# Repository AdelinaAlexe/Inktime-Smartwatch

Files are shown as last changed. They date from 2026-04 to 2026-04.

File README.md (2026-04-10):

# InkTime Smartwatch

**Author:** Adelina Maria Alexe

**License:** [GNU GPLv3](LICENSE)  

---

## Architecture & Block Diagram

The core architecture relies on the **nRF52840 SoC** to manage all peripheral communication and wireless connectivity. To guarantee system stability and maximize battery utilization, power delivery is strictly regulated by an **RT6160 Buck-Boost converter**, which maintains a constant 3.3V rail for all active components.

**Block Diagram**
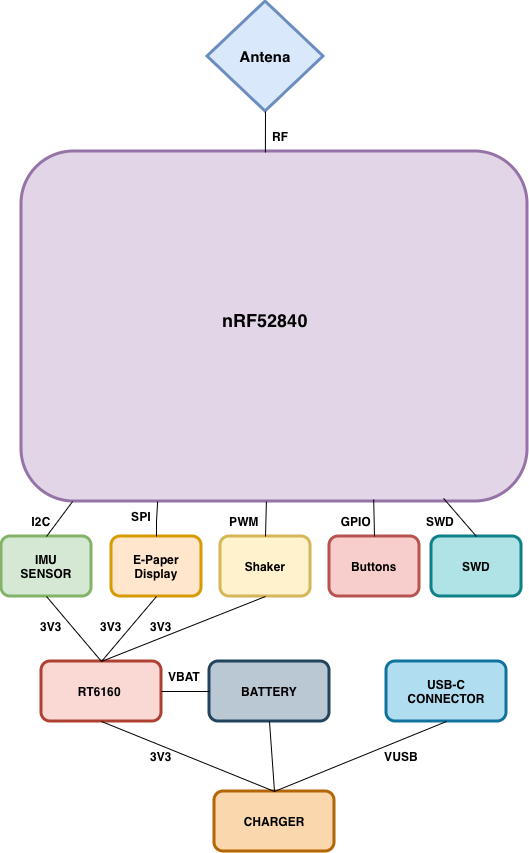
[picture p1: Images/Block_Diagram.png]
Block Diagram


---

## Bill of Materials

| Designator(s) | JLC | Package | Description | Referance |
| :--- | :--- | :--- | :--- | :--- |
| **U1** | C3606653 | QFN-48 | nRF52840 BLE 5.4 Microcontroller | [Referance](https://www.lcsc.com/datasheet/C3606653.pdf) |
| **IC1** | C3682423 | DSBGA-8 | BQ25180 Li-Ion/Polymer Charger IC | [Referance](https://www.ti.com/cn/lit/ds/symlink/bq25180.pdf?ts=1775594237116) |
| **IC2** | C81079 | DSBGA-9 | DRV2605 Haptic Motor Driver | [Referance](https://www.ti.com/cn/lit/gpn/drv2605) |
| **IC3** | C189517 | LGA-12 | BMA423 Triaxial Accelerometer (IMU) | [Referance](https://www.lcsc.com/datasheet/C189517.pdf) |
| **IC9** | C7065276 | WLCSP-15B | RT6160 Buck-Boost Regulator | [Referance](https://wmsc.lcsc.com/wmsc/upload/file/pdf/v2/lcsc/2312271436_Richtek-Tech-RT6160AWSC_C7065276.pdf) |
| **U2** | C2682616 | DFN-8-EP | MAX17048G I2C Battery Fuel Gauge | [Referance](https://www.lcsc.com/datasheet/lcsc_datasheet_2410121738_Analog-Devices-Inc--Maxim-Integrated-MAX17048G-T10_C2682616.pdf) |
| **J1** | C122434 | SMD 0.5mm | 24-Pin FPC Connector (E-Paper Display) | [Referance](https://www.molex.com/content/dam/molex/molex-dot-com/products/automated/en-us/salesdrawingpdf/503/503480/5034802400_sd.pdf) |
| **J4** | C709357 | SMD Type-C | Type-C USB 16P Connector | [Referance](https://www.lcsc.com/datasheet/lcsc_datasheet_2404191039_Shenzhen-Kinghelm-Elec-KH-TYPE-C-16P_C709357.pdf) |
| **ANT1** | C2917717 | 1206 | 2.45GHz Patch Antenna (0.5dBi) | [Referance](https://www.lcsc.com/datasheet/lcsc_datasheet_2404021210_Johanson-Dielectrics-2450AT18B100E_C2917717.pdf) |
| **X1** | C9009 | SMD3225 | 32MHz Crystal Oscillator | [Referance](https://www.lcsc.com/datasheet/lcsc_datasheet_2403291504_YXC-Crystal-Oscillators-X322532MOB4SI_C9009.pdf) |
| **X2** | C32346 | SMD3215 | 32.768kHz Crystal Oscillator | [Referance](https://www.lcsc.com/datasheet/lcsc_datasheet_2404180925_Seiko-Epson-Q13FC13500004_C32346.pdf) |
| **SW_UP, SW_ENT, SW_DN** | C569760 | SMD 3.9x2.9 | Tactile Switches (IP67) | [Referance](https://wmsc.lcsc.com/wmsc/upload/file/pdf/v2/lcsc/2301111010_PANASONIC-EVPAKE31A_C569760.pdf) |
| **D2, D4, D5** | C82046 | SOD-123 | MBR0530 Schottky Diode (30V, 0.5A) | [Referance](https://www.lcsc.com/datasheet/lcsc_datasheet_2304140030_onsemi-MBR0530T1G_C82046.pdf) |
| **D3** | C2969755 | SOT-23-6L | USBLC6-2SC6Y ESD Protection Array | [Referance](https://wmsc.lcsc.com/wmsc/upload/file/pdf/v2/lcsc/2211080730_STMicroelectronics-USBLC6-2SC6Y_C2969755.pdf) |
| **Q1** | C2564 | TO-220AB | IRF4905PBF P-Channel MOSFET | [Referance](https://www.lcsc.com/datasheet/lcsc_datasheet_1809041724_Infineon-Technologies-IRF4905PBF_C2564.pdf) |
| **Q3** | C469327 | SOT-323 | Si1308EDL N-Channel MOSFET | [Referance](https://www.lcsc.com/datasheet/lcsc_datasheet_1912202016_Vishay-Intertech-SI1308EDL-T1-GE3_C469327.pdf) |
| **L1, L2, L3** | C12669 | 0402 | Generic Chip Inductor (27nH) | [Referance](https://www.lcsc.com/datasheet/lcsc_datasheet_2304140030_Murata-Electronics-LQG15HS27NJ02D_C12669.pdf) |
| **L5** | C1329646 | SMD 4.8x4.8 | 4.7uH Power Inductor (AEC-Q200) | [Referance](https://wmsc.lcsc.com/wmsc/upload/file/pdf/v2/lcsc/2304140030_BOURNS-SRR4828A-4R7Y_C1329646.pdf) |
| **L7** | C5832368 | 1008 | 470nH Power Inductor | [Referance](https://wmsc.lcsc.com/wmsc/upload/file/pdf/v2/lcsc/2306021632_cjiang--Changjiang-Microelectronics-Tech-FTC252012SR47MBCA_C5832368.pdf) |
| **J2** | C90533 | P=1mm | 6 POS Cable Adapter | [Referance](https://wmsc.lcsc.com/wmsc/upload/file/pdf/v2/lcsc/1810141506_LX-FFC6P1-0mm7CM_C90533.pdf) |
| **Resistors (Group)** | C3920633 | 0201 | 7.68k Thin Film Resistors (±0.5%) | [Referance](https://wmsc.lcsc.com/wmsc/upload/file/pdf/v2/lcsc/2404081048_TE-Connectivity-CPF0201B511RE1_C3920633.pdf) |
| **Capacitors (Group)** | C9900156064 | 0201 | Generic Chip Capacitors | [Referance](https://ds.yuden.co.jp/TYCOMPAS/or/download?pn=MLAST063SCG681JFNA01&fileType=CA) |
| **C23, C27, C34, C42** | C21012218 | - | Special Chip Capacitors | [Referance](https://jlc-prod-smt.oss-eu-central-1.aliyuncs.com/smtDataManualFile/8603520985945550848-C21012218.pdf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) |
| **C24, C25, C33, C39** | C9900179830 | 0402 | 0402 Metric Capacitors | N/A |
| **SJ1** | N/A | Copper | Solder Jumper (Leave Open) | N/A |
| **TP** | N/A | Copper | Test Pads | N/A |

---

## Hardware Specifications & Functionality

InkTime is engineered from the ground up for extreme power efficiency. By pairing a deeply optimized microcontroller with an E-Ink display, the device maintains readability in direct sunlight while drawing virtually no power during static image display.

### -> Processing & Connectivity
* **Microcontroller (Nordic nRF52840):** Features an ARM Cortex-M4F core clocked at 64 MHz. It provides native support for Bluetooth 5.4 (BLE) and boasts exceptional deep-sleep currents in the micro-amp range. 

### -> Power Management System
* **Charging Interface:** The **BQ25180** IC handles USB-C battery charging utilizing a strict Constant Current/Constant Voltage (CC/CV) profile, alongside integrated overvoltage and thermal protection.
* **Voltage Regulation:** We opted for the **RT6160** Buck-Boost converter over a standard LDO. This allows the system to maintain a rock-solid **3.3V** output even when the Li-Po battery voltage sags down to 3.0V, squeezing every last drop of usable capacity from the cell.
* **Battery Monitoring:** The **MAX17048G** Fuel Gauge interfaces via I2C to provide high-resolution State of Charge (SoC) metrics without requiring complex shunt resistor calculations.

### -> Peripherals & Busses
* **SPI Bus (Display):** Dedicated entirely to the 1.54" E-Paper display via a 24-pin FPC connector (J1). SPI ensures the high bandwidth needed for screen refreshes without bottlenecking other sensors.
* **I2C Bus (Sensors):** A shared I2C bus routes data from the **BMA423** IMU (used for step counting and wake-on-wrist-raise), the **MAX17048G** fuel gauge, and the **DRV2605YZFR** haptic driver.
* **Haptics:** Silent, localized haptic feedback is generated by a vibration motor driven by the **DRV2605YZFR** via PWM signals from the MCU.

### -> Power Consumption & Autonomy Analysis
The device is powered by a compact **250 mAh Li-Po cell** (Akyga LP502030). Given the E-Ink display's zero-power static state, the system's current draw is highly optimized:

* **Sleep State (MCU + BLE Advertising):** ~35 µA
* **Active Sensor Polling:** ~120 µA
* **Display Refresh Cost (Averaged per minute):** ~25 µA
* **Estimated Average Current (I_avg):** 180 µA (0.18 mA)

**Theoretical Battery Life:** `T = 250 mAh / 0.18 mA ≈ 1389 hours`

Accounting for real-world environmental factors, battery degradation, and dynamic haptic usage, the practical autonomy is rated at **9 to 14 days** per charge.

---

## MCU Pinout & Interface Mapping

| Interface / Component | Signal | nRF52840 Pin | I/O | Engineering Rationale |
| :--- | :--- | :--- | :--- | :--- |
| **E-Ink Display** | SPI SCK | **P0.11** | Output | High-speed clock mapped to Port 0 for EasyDMA access. |
| **E-Ink Display** | SPI MOSI | **P0.12** | Output | Display data transmission. |
| **E-Ink Display** | SPI CS | **P0.13** | Output | Active-low Chip Select. |
| **E-Ink Display** | Data/Command | **P0.14** | Output | Toggles between command modes and payload data. |
| **E-Ink Display** | Reset | **P0.15** | Output | Hardware reset trigger for E-Ink initialization. |
| **E-Ink Display** | Busy | **P0.16** | Input | Halts MCU operations while the display refreshes. |
| **I2C Bus** | SDA | **P0.26** | I/O | Shared data line for IMU, Fuel Gauge, and Haptics. |
| **I2C Bus** | SCL | **P0.27** | Output | Shared clock line optimized for low-power I2C routing. |
| **Button (Up)** | GPIO | **P1.07** | Input | Isolated on Port 1 to prevent high-speed signal noise. |
| **Button (Enter)** | GPIO | **P1.08** | Input | Includes internal pull-up resistor. |
| **Button (Down)** | GPIO | **P1.09** | Input | UI navigation control. |
| **Haptic Motor** | PWM | **P1.02** | Output | Modulates vibration intensity via PWM. |
| **PMIC Control** | DC/DC EN | **P0.18** | Output | Enables/Disables the RT6160 during extreme deep sleep. |
| **IMU Sensor** | INT1 | **P0.25** | Input | Hardware interrupt designated for "double-tap" wake up. |

### Design Justifications:
- **Port Segregation:** Port 0 is strictly allocated to high-speed digital busses (SPI/I2C) to leverage Nordic's **EasyDMA**, offloading data transfer from the CPU. Port 1 is reserved for physical buttons, providing physical layout isolation from high-frequency switching noise, thereby preventing false button triggers (ghosting).
- **SPI Trace Routing:** Pins P0.11 through P0.16 were selected due to their physical grouping on the silicon die, allowing for a tight, length-matched routing channel to the FPC connector.
- **NFC Provisioning:** Pins P0.09 and P0.10 were deliberately left disconnected. Their internal capacitance differs from standard GPIOs due to their native NFC capabilities. Keeping them free leaves the door open for future hardware revisions featuring contactless technology.

---

## PCB Design Log & Decisions

The PCB layout adheres to strict Design for Manufacturing (DFM) tolerances required for high-density wearable electronics:

* **Single-Layer Component Placement:** Due to severe vertical clearance constraints inside the chassis, **all 49 components are mounted on the TOP layer**. The BOTTOM layer is primarily utilized for an unbroken ground plane and non-critical signal routing.
* **Miniaturization (0201 Packages):** To achieve the required routing density on a single layer, all standard passive components (resistors, small capacitors) were downsized to **0201** imperial footprints.
* **Signal Integrity & Decoupling:** **100nF** bypass capacitors are placed aggressively close—within **0.5mm**—to the power pins of the nRF52840 to minimize parasitic loop inductance.
* **Trace Width Constraints:** Power delivery rails (VCC, 3V3, VBAT) are routed at a robust **0.3mm** width to prevent voltage drops during peak current spikes (e.g., haptic motor activation or BLE transmission). Standard data traces are kept at **0.15mm**.
* **RF Optimization (Keep-Out & Stitching):** A strict keep-out zone (void of any copper, traces, or ground planes) was enforced through all PCB layers directly beneath the 2.4GHz chip antenna. Additionally, heavy **via stitching** was applied across the board—particularly around the RF path—to tie the top and bottom ground planes together, drastically lowering reference impedance.

---

## Hardware Renderings & Visuals

**Final Design**
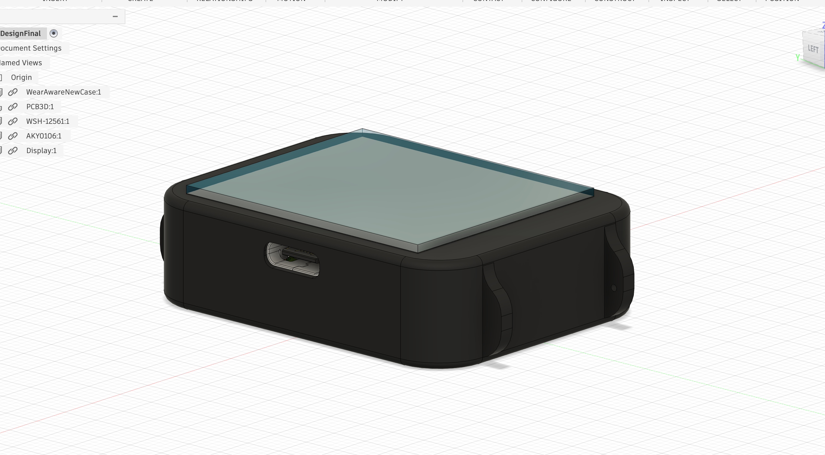
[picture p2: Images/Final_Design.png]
Final Design


**PCB 3D**
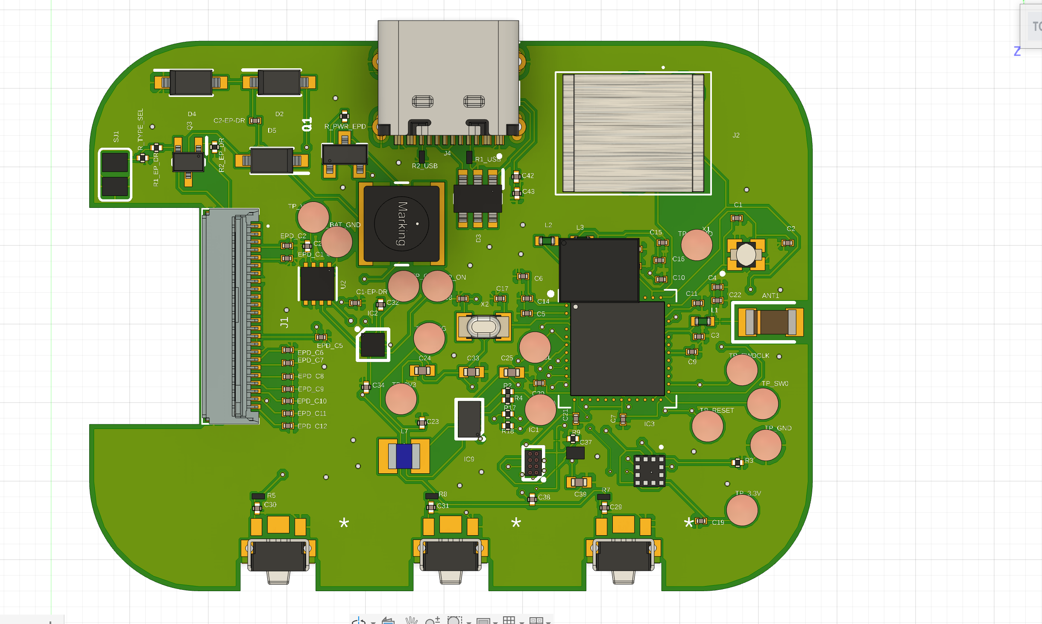
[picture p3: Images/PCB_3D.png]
PCB 3D


**Final Design Exploded**
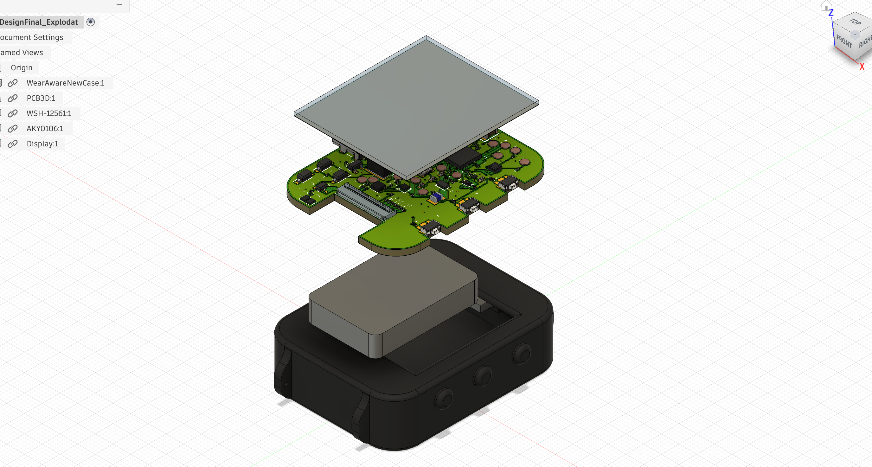
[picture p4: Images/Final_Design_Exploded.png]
Exploded View


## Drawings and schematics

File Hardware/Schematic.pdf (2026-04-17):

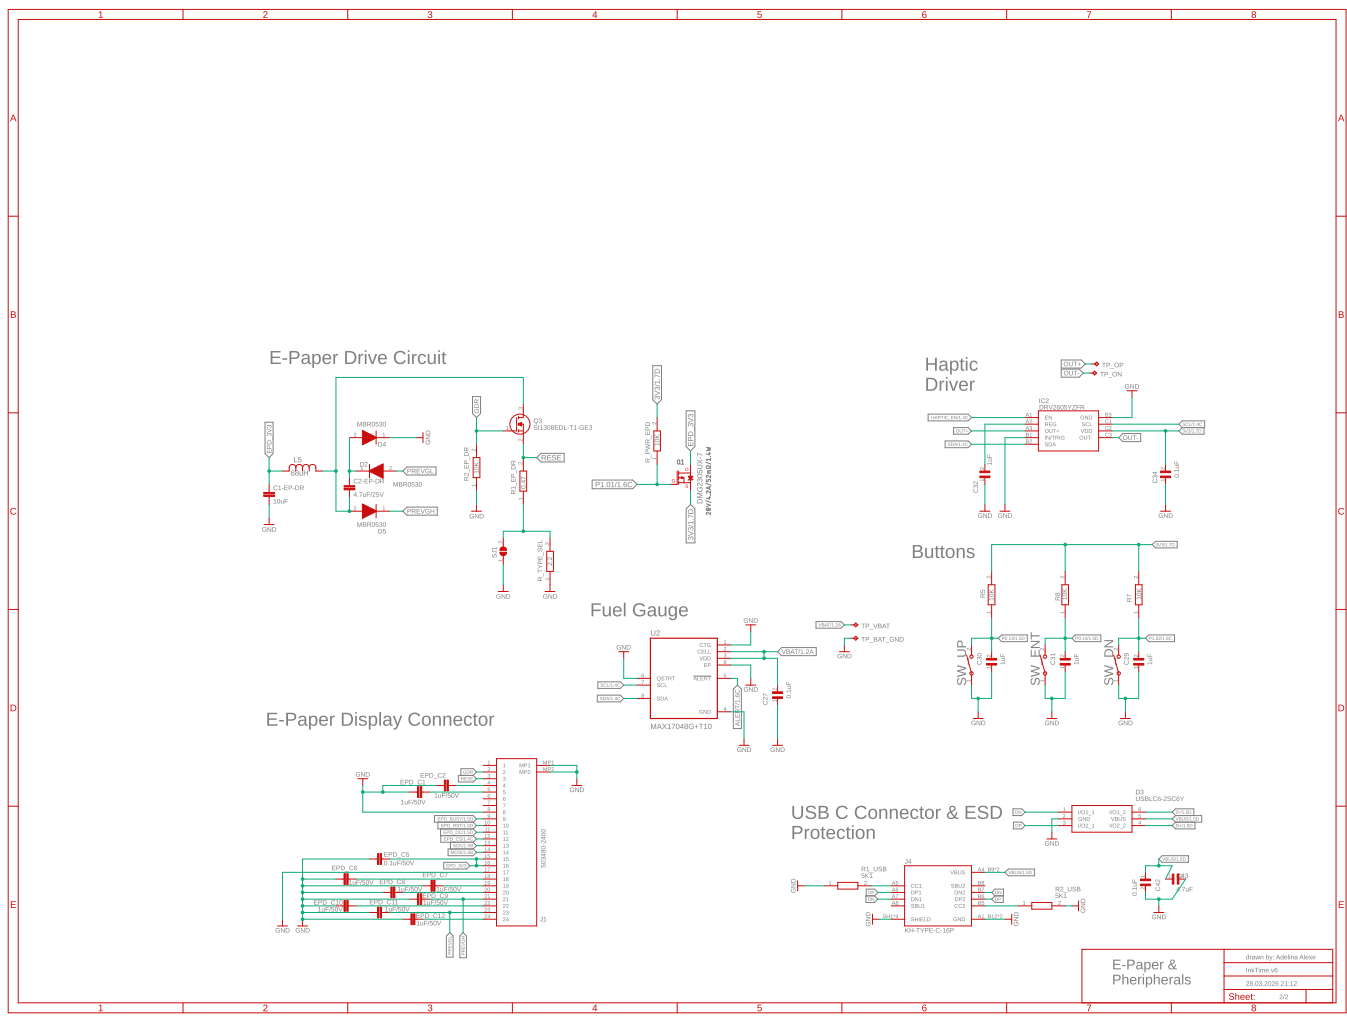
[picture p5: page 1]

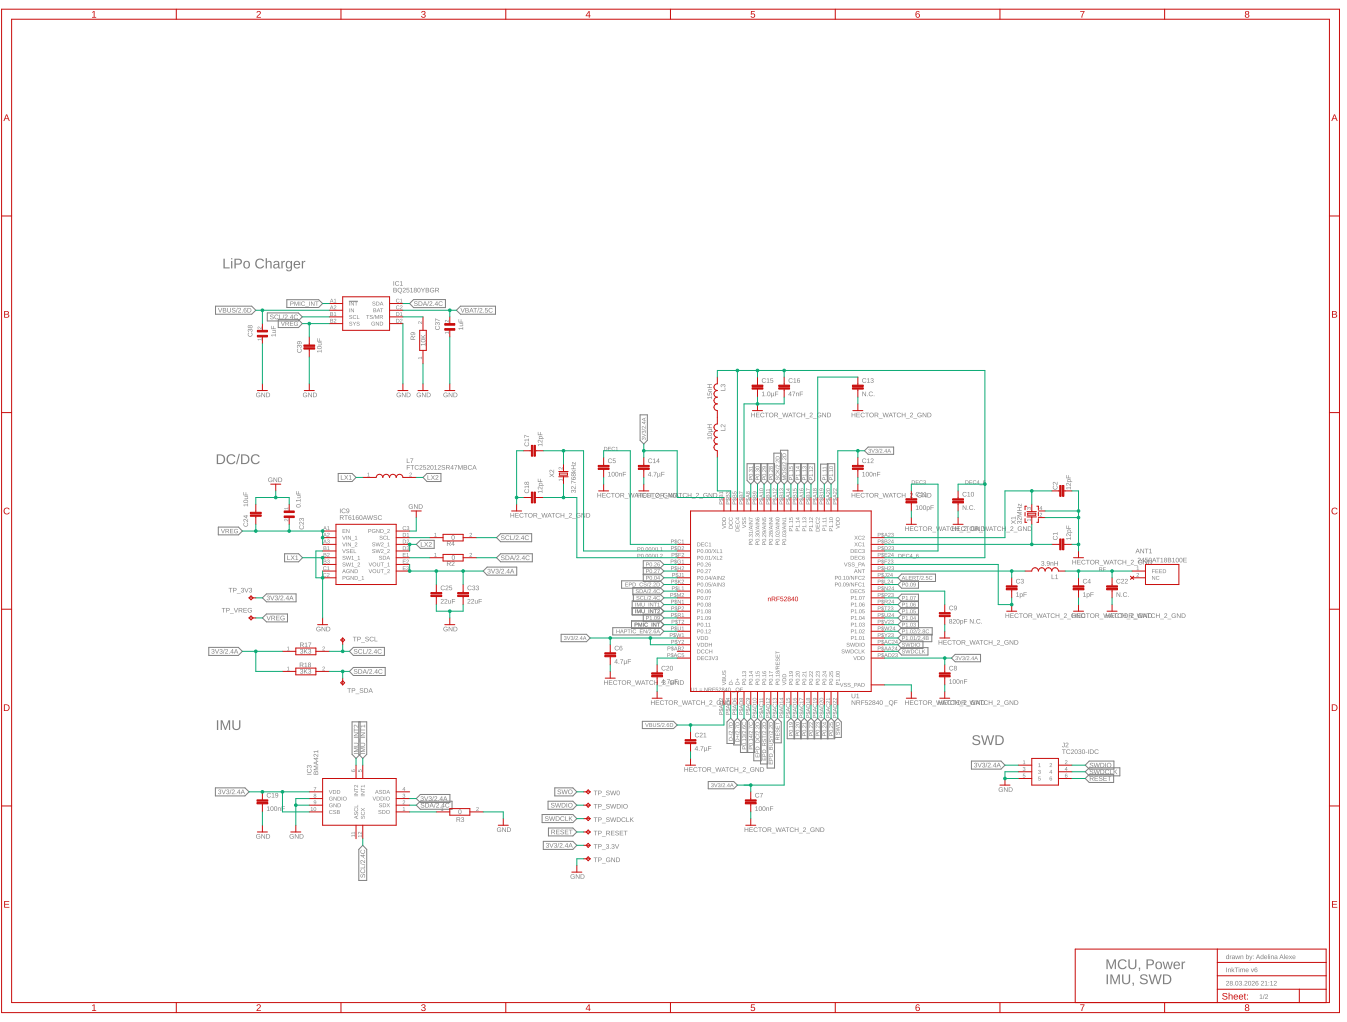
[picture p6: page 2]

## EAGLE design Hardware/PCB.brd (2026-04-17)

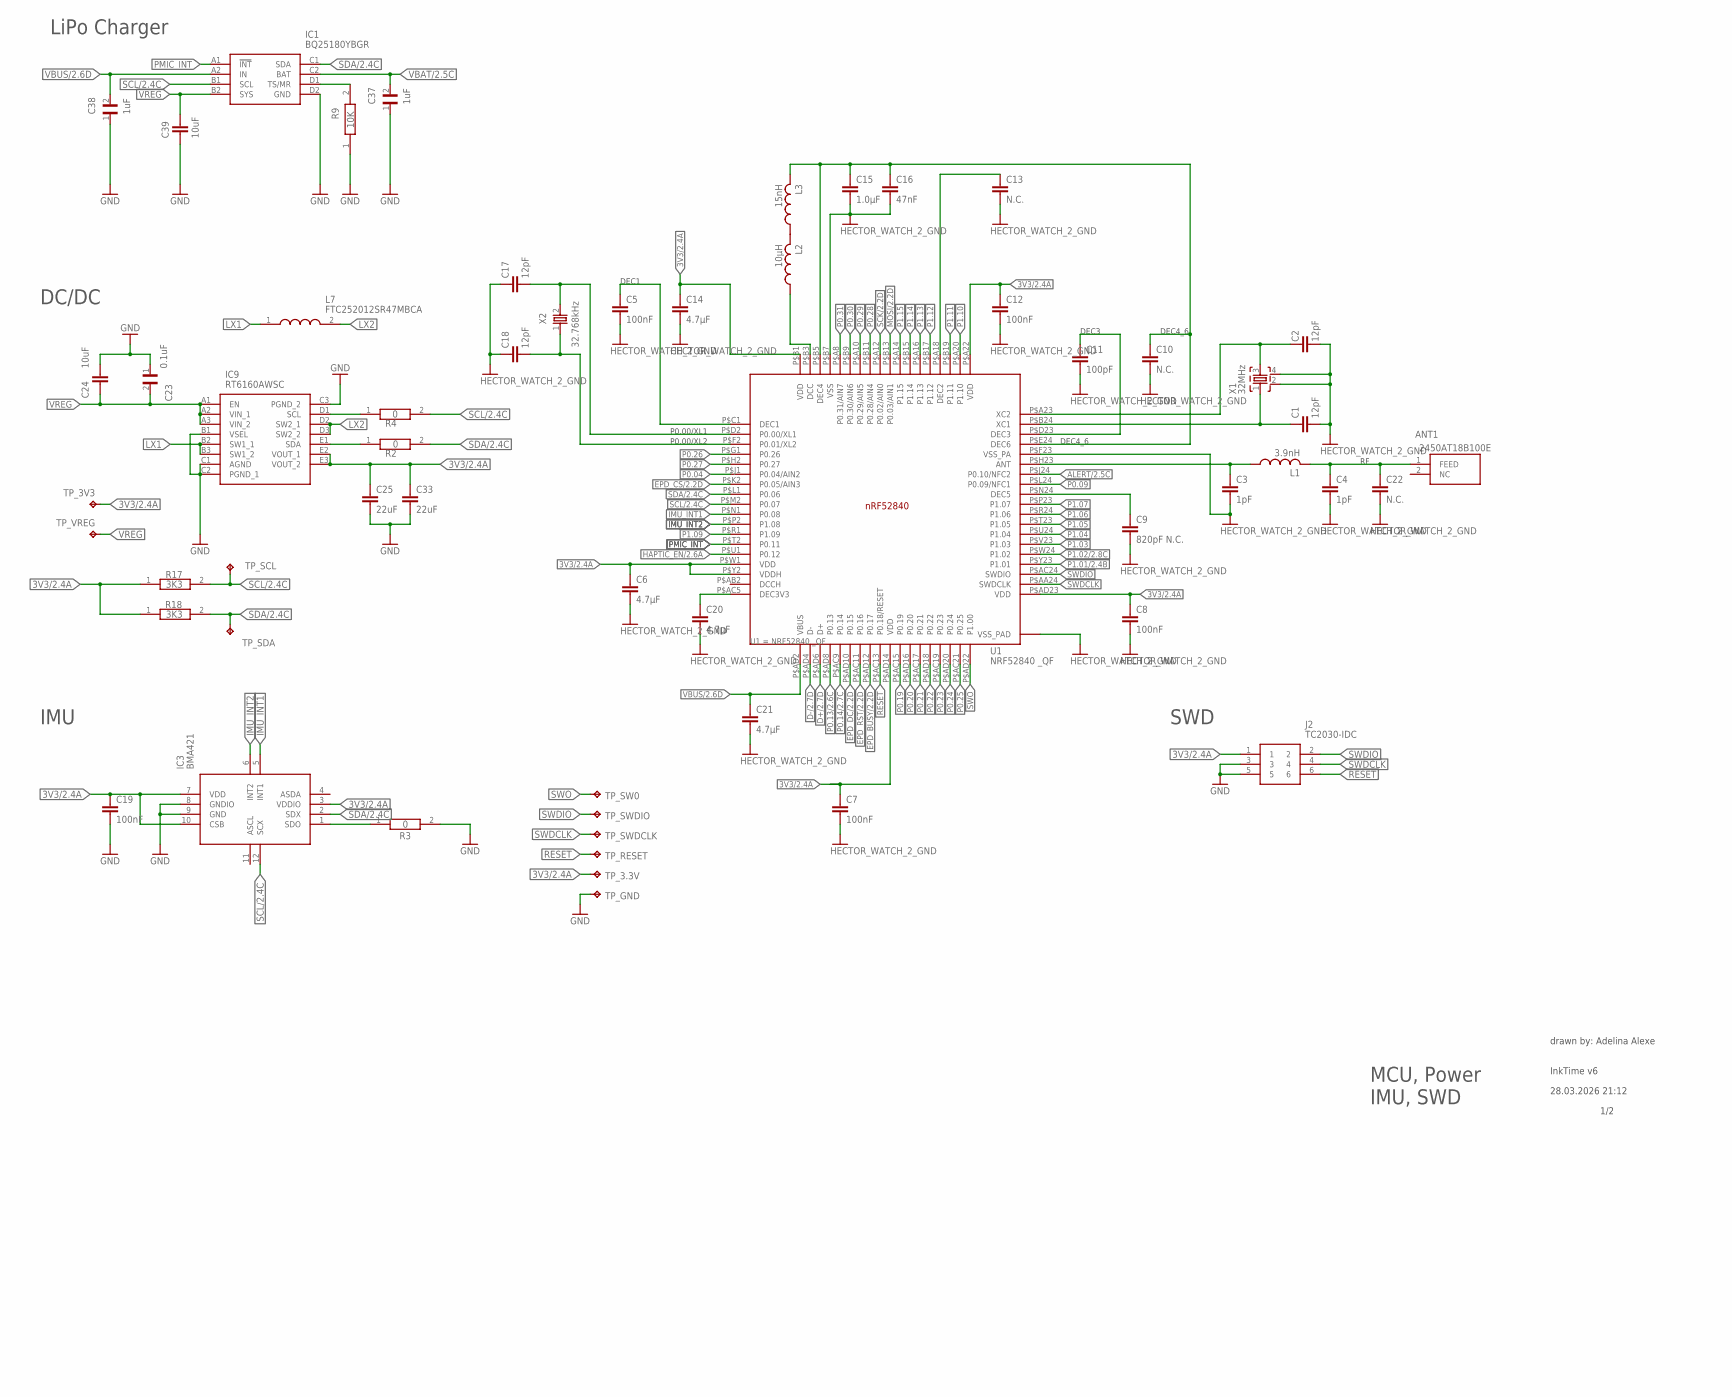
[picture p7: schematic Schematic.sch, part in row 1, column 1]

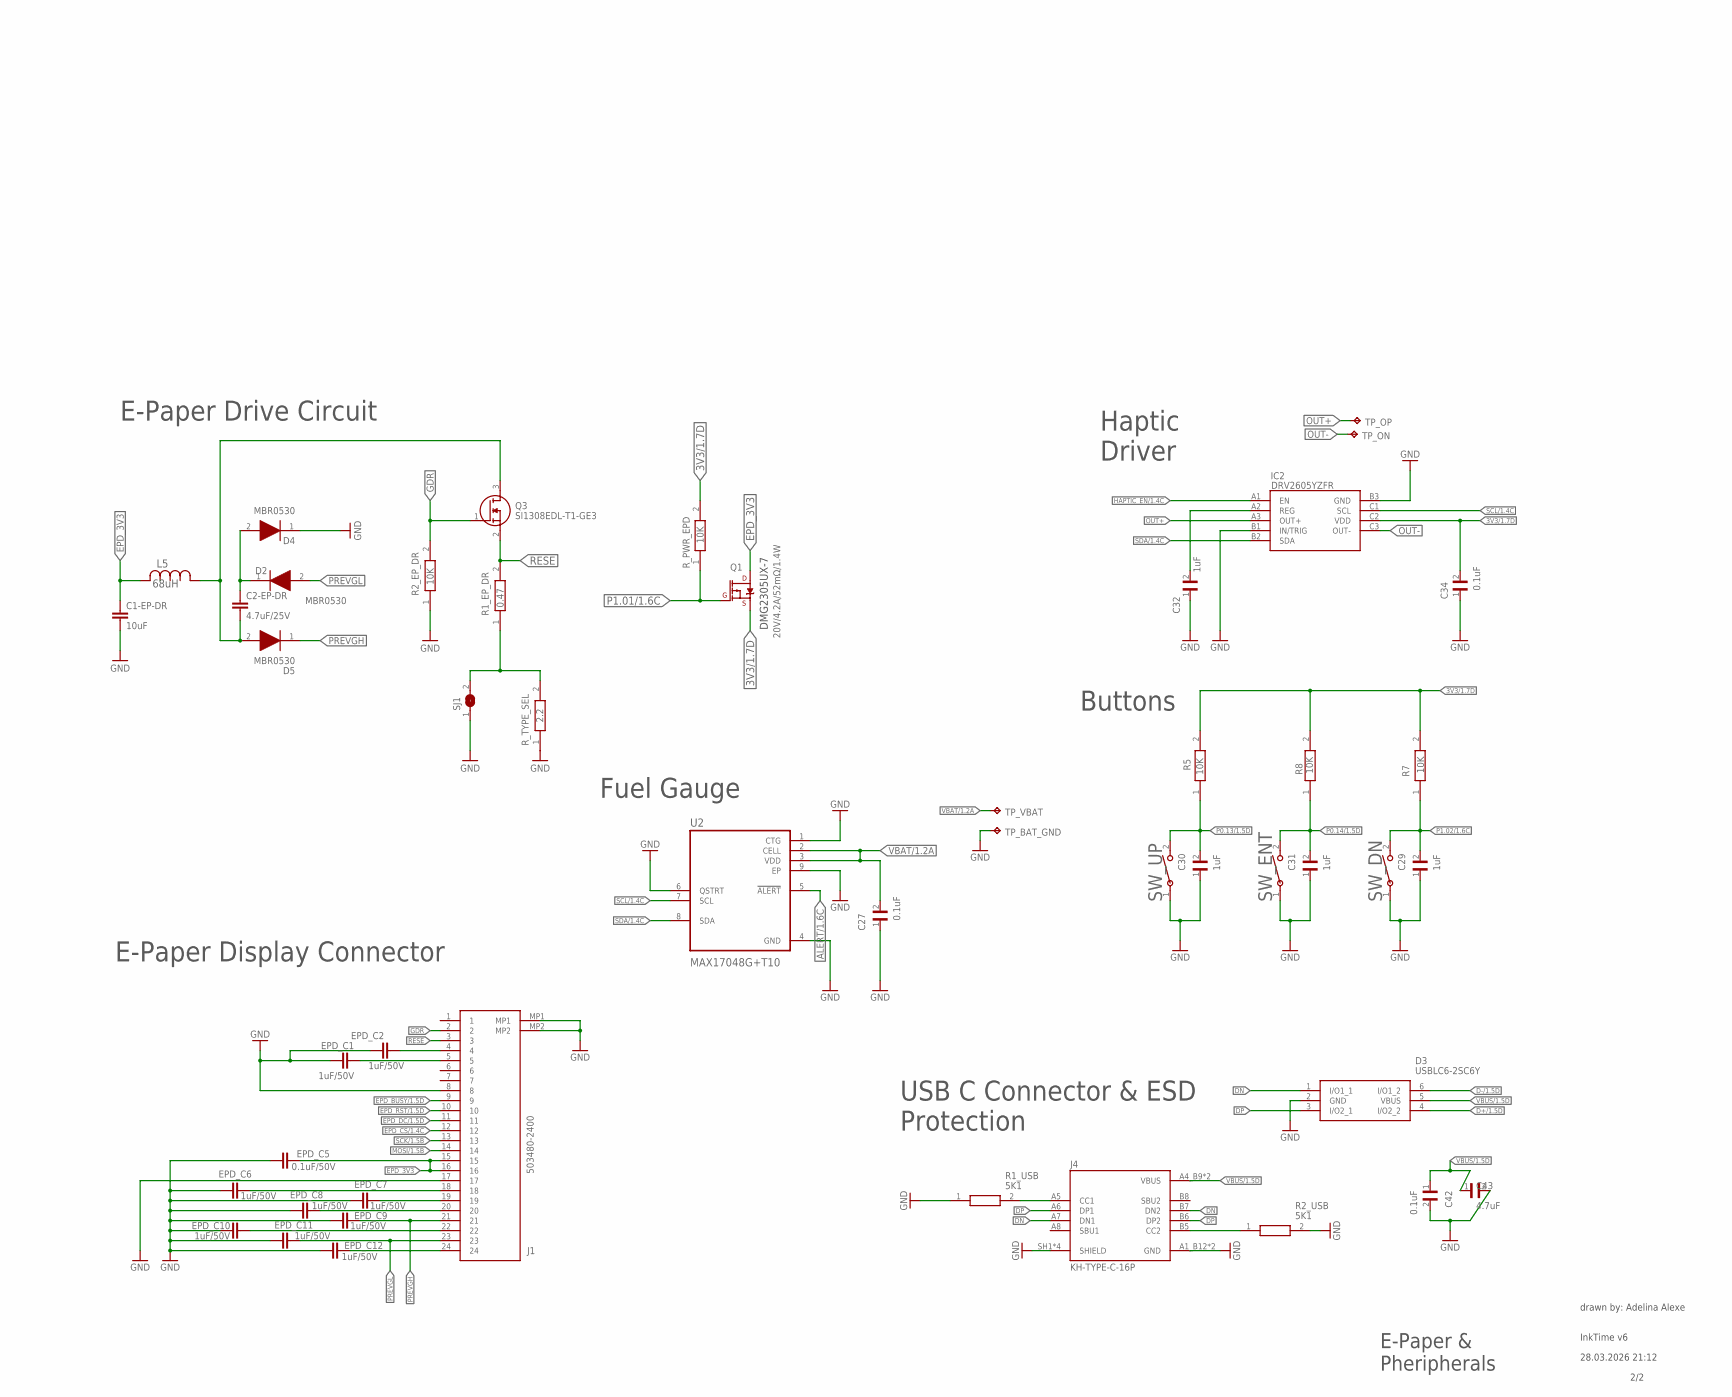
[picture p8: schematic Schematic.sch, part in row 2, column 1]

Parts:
ANT1: 2450AT18B100E; 2450AT18B100E_ANTC3216X140N
C1, C2, C17, C18: 12pF; NORDIC_NRF_3_RESC0201_L
C1-EP-DR: 10uF; NORDIC_NRF_3_RESC0201_L
C2-EP-DR: 4.7uF/25V; NORDIC_NRF_3_RESC0201_L
C3, C4: 1pF; NORDIC_NRF_3_RESC0201_L
C5, C7, C8, C12, C19: 100nF; NORDIC_NRF_3_RESC0201_L
C6, C14, C20, C21: 4.7µF; NORDIC_NRF_3_RESC0201_L
C9: 820pF N.C.; NORDIC_NRF_3_RESC0201_L
C10, C13, C22: N.C.; NORDIC_NRF_3_RESC0201_L
C11: 100pF; NORDIC_NRF_3_RESC0201_L
C15: 1.0µF; NORDIC_NRF_3_RESC0201_L
C16: 47nF; NORDIC_NRF_3_RESC0201_L
C23, C27, C34, C42: 0.1uF; GRM011R60J152KE01L_1_0201
C24, C39: 10uF; PERFECT_0402_0402
C25, C33: 22uF; PERFECT_0402_0402
C29, C30, C31, C32, C38: 1uF; GRM011R60J152KE01L_1_0201
C37: 1uF; GRM011R60J152KE01L_2_CAPC0201X13N
C43: 4.7uF; GRM011R60J152KE01L_1_0201
D2, D4, D5: MBR0530; ESP32_C6_LIBRARY_5_SOD3716X135N
D3: USBLC6-2SC6Y; ESP32_C6_LIBRARY_3_SOT95P280X145-6N
EPD_C1, EPD_C2, EPD_C6, EPD_C7, EPD_C8, EPD_C9, EPD_C10, EPD_C11, EPD_C12: 1uF/50V; NORDIC_NRF_3_RESC0201_L
EPD_C5: 0.1uF/50V; NORDIC_NRF_3_RESC0201_L
IC1: BQ25180YBGR; BQ25180YBGR_BGA8C40P2X4_100X155X50
IC2: DRV2605YZFR; DRV2605YZFR_BGA9C50P3X3_144X144X62
IC3: BMA421; BMA423_BMA423
IC9: RT6160AWSC; RT6160AWSC_BGA15C40P3X5_140X230X60
J1: 503480-2400; 503480-2400_5034802400
J2: TC2030-IDC; TC2030-IDC_TC2030IDC
J4: KH-TYPE-C-16P; KH-TYPE-C-16P_KINGHELM_KH-TYPE-C-16P
L1: 3.9nH; NORDIC_NRF_2_RESC0402_L
L2: 10µH; NORDIC_NRF_2_RESC0402_L
L3: 15nH; NORDIC_NRF_2_RESC0402_L
L5: 68uH; ESP32_C6_LIBRARY_2_IND_4828-WE-TPC_WRE
L7: FTC252012SR47MBCA; MLP2016SR47MT0S1_INDC2016X100N
Q1: 20V/4.2A/52mΩ/1.4W; ESP32_C6_LIBRARY_4_ESP32_C6_LIBRARY_4_ESP32_C6_LIBRARY_4_ES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
Q3: SI1308EDL-T1-GE3; ESP32_C6_LIBRARY_6_SOT65P210X110-3N
R1_EP_DR: 0.47; CPF0201D7K68C1_0201
R1_USB, R2_USB: 5K1; ERA-1AEB3401C_0201
R2, R3, R4: 0; CPF0201D7K68C1_0201
R2_EP_DR, R9: 10K; CPF0201D7K68C1_0201
R5, R7, R8: 10K; ERA-1AEB3401C_0201
R17, R18: 3K3; CPF0201D7K68C1_0201
R_PWR_EPD: 10K; CPF0201D7K68C1_0201
R_TYPE_SEL: 2.2; CPF0201D7K68C1_0201
SJ1: ESP32_C6_LIBRARY_7_JUMPER_SJ
SW_DN: 2025-10-22_07-23-44_LIBRARY_EVP-AKE31ASW_EVP-AKE3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; 2025-10-22_07-23-44_LIBRARY_SW_EVP-AKE31A_PAN
SW_ENT: 2025-10-22_07-23-44_LIBRARY_EVP-AKE31ASW_EVP-AKE3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; 2025-10-22_07-23-44_LIBRARY_SW_EVP-AKE31A_PAN
SW_UP: 2025-10-22_07-23-44_LIBRARY_EVP-AKE31ASW_EVP-AKE3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; 2025-10-22_07-23-44_LIBRARY_SW_EVP-AKE31A_PAN
TP_3.3V, TP_3V3: HECTOR_WATCH_1_TPTP20R; HECTOR_WATCH_1_TP20R
TP_BAT_GND: HECTOR_WATCH_1_TPTP20R; HECTOR_WATCH_1_TP20R
TP_GND: HECTOR_WATCH_1_TPTP20R; HECTOR_WATCH_1_TP20R
TP_ON: HECTOR_WATCH_1_TPTP20R; HECTOR_WATCH_1_TP20R
TP_OP: HECTOR_WATCH_1_TPTP20R; HECTOR_WATCH_1_TP20R
TP_RESET: HECTOR_WATCH_1_TPTP20R; HECTOR_WATCH_1_TP20R
TP_SCL: HECTOR_WATCH_1_TPTP20R; HECTOR_WATCH_1_TP20R
TP_SDA: HECTOR_WATCH_1_TPTP20R; HECTOR_WATCH_1_TP20R
TP_SW0: HECTOR_WATCH_1_TPTP20R; HECTOR_WATCH_1_TP20R
TP_SWDCLK: HECTOR_WATCH_1_TPTP20R; HECTOR_WATCH_1_TP20R
TP_SWDIO: HECTOR_WATCH_1_TPTP20R; HECTOR_WATCH_1_TP20R
TP_VBAT: HECTOR_WATCH_1_TPTP20R; HECTOR_WATCH_1_TP20R
TP_VREG: HECTOR_WATCH_1_TPTP20R; HECTOR_WATCH_1_TP20R
U1: NRF52840 _QF; NORDIC_NRF_4_AQFN50P700X700X85_HS-74N
U2: MAX17048G+T10; ESP32_C6_LIBRARY_SON50P200X200X80-9N
X1: 32MHz; NORDIC_NRF_BT-XTAL_2016_N
X2: 32.768kHz; NORDIC_NRF_1_XTAL_3215_N

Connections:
3V3/1.7D: C34.2, IC2.C2 (VDD), Q1.2 (S), R5.2, R7.2, R8.2, R_PWR_EPD.2
3V3/2.4A: C6.1, C7.1, C8.1, C12.1, C14.1, C19.1, C25.1, C33.1, IC3.3 (VDDIO), IC3.7 (VDD), IC3.10 (CSB), IC9.E2 (VOUT_1), IC9.E3 (VOUT_2), J2.1, R17.1, R18.1, TP_3.3V.TP, TP_3V3.TP, U1.P$A22 (VDD), U1.P$AD14 (VDD), U1.P$AD23 (VDD), U1.P$B1 (VDD), U1.P$W1 (VDD), U1.P$Y2 (VDDH)
ALERT/1.6C: U2.5 (!ALERT)
ALERT/2.5C: U1.P$J24 (P0.10/NFC2)
D+/1.5D: D3.4 (I/O2_2)
D+/2.7D: U1.P$AD6 (D+)
D-/1.5D: D3.6 (I/O1_2)
D-/2.7D: U1.P$AD4 (D-)
DN: D3.1 (I/O1_1), J4.A7 (DN1), J4.B7 (DN2)
DP: D3.3 (I/O2_1), J4.A6 (DP1), J4.B6 (DP2)
EPD_3V3: C1-EP-DR.1, EPD_C5.2, J1.15, J1.16, L5.2, Q1.3 (D)
EPD_BUSY/1.5D: J1.9
EPD_BUSY/2.2D: U1.P$AD12 (P0.17)
EPD_CS/1.4C: J1.12
EPD_CS/2.2D: U1.P$K2 (P0.05/AIN3)
EPD_DC/1.5D: J1.11
EPD_DC/2.2D: U1.P$AD10 (P0.15)
EPD_RST/1.5D: J1.10
EPD_RST/2.2D: U1.P$AC11 (P0.16)
GDR: J1.2, Q3.1 (G), R2_EP_DR.2
GND: C1.2, C1-EP-DR.2, C2.1, C3.2, C4.2, C5.2, C6.2, C7.2, C8.2, C9.2, C10.2, C11.2, C12.2, C13.2, C14.2, C15.2, C16.2, C17.1, C18.1, C19.2, C20.2, C21.2, C22.2, C23.1, C24.1, C25.2, C27.1, C29.1, C30.1, C31.1, C32.1, C33.2, C34.1, C37.1, C38.1, C39.2, C42.2, C43.2, D3.2 (GND), D4.1 (K), EPD_C1.1, EPD_C2.1, EPD_C5.1, EPD_C6.1, EPD_C7.1, EPD_C8.1, EPD_C9.1, EPD_C10.1, EPD_C11.1, EPD_C12.1, IC1.D2 (GND), IC2.B1 (IN/TRIG), IC2.B3 (GND), IC3.8 (GNDIO), IC3.9 (GND), IC9.B1 (VSEL), IC9.C1 (AGND), IC9.C2 (PGND_1), IC9.C3 (PGND_2), J1.8, J1.17, J1.MP1, J1.MP2, J2.3, J2.5, J4.A1_B12 (GND), J4.A12_B1 (GND), J4.SH1 (SHIELD), J4.SH2 (SHIELD), J4.SH3 (SHIELD), J4.SH4 (SHIELD), R1_USB.1, R2_EP_DR.1, R2_USB.2, R3.2, R9.1, R_TYPE_SEL.1, SJ1.1, SW_DN.1, SW_ENT.1, SW_UP.1, TP_BAT_GND.TP, TP_GND.TP, U1.P$74 (VSS_PAD), U1.P$75 (VSS_PAD), U1.P$76 (VSS_PAD), U1.P$77 (VSS_PAD), U1.P$78 (VSS_PAD), U1.P$79 (VSS_PAD), U1.P$80 (VSS_PAD), U1.P$81 (VSS_PAD), U1.P$82 (VSS_PAD), U1.P$83 (VSS_PAD), U1.P$84 (VSS_PAD), U1.P$85 (VSS_PAD), U1.P$86 (VSS_PAD), U1.P$87 (VSS_PAD), U1.P$88 (VSS_PAD), U1.P$89 (VSS_PAD), U1.P$90 (VSS_PAD), U1.P$B7 (VSS), U1.P$F23 (VSS_PA), U2.1 (CTG), U2.4 (GND), U2.6 (QSTRT), U2.9 (EP), X1.2, X1.4
HAPTIC_EN/1.4C: IC2.A1 (EN)
HAPTIC_EN/2.6A: U1.P$U1 (P0.12)
IMU_INT1: IC3.5 (INT1), U1.P$N1 (P0.08)
IMU_INT2: IC3.6 (INT2), U1.P$P2 (P1.08)
LX1: IC9.B2 (SW1_1), IC9.B3 (SW1_2), L7.1
LX2: L7.2
MOSI/1.5B: J1.14
MOSI/2.2D: U1.P$B13 (P0.03/AIN1)
unnamed: IC1.D1 (TS/MR), R9.2
unnamed: L2.1, U1.P$B3 (DCC)
unnamed: IC3.1 (SDO), R3.1
unnamed: L2.2, L3.1
unnamed: C10.1, C15.1, C16.1, L3.2, U1.P$B5 (DEC4), U1.P$E24 (DEC6)
unnamed: C13.1, U1.P$A18 (DEC2)
unnamed: C5.1, U1.P$C1 (DEC1)
unnamed: IC9.E1 (SDA), R2.1
unnamed: C17.2, U1.P$D2 (P0.00/XL1), X2.2
unnamed: IC9.D2 (SW2_1), IC9.D3 (SW2_2)
unnamed: IC9.D1 (SCL), R4.1
unnamed: C18.2, U1.P$F2 (P0.01/XL2), X2.1
unnamed: C20.1, U1.P$AC5 (DEC3V3)
unnamed: C9.1, U1.P$N24 (DEC5)
unnamed: C3.1, L1.1, U1.P$H23 (ANT)
unnamed: ANT1.1 (FEED), C4.1, C22.1, L1.2
unnamed: C11.1, U1.P$D23 (DEC3)
unnamed: C1.1, U1.P$B24 (XC1), X1.1
unnamed: C2.2, U1.P$A23 (XC2), X1.3
unnamed: C2-EP-DR.1, D2.1 (K), D4.2 (A)
unnamed: C2-EP-DR.2, D5.2 (A), L5.1, Q3.3 (D)
unnamed: R1_EP_DR.1, R_TYPE_SEL.2, SJ1.2
unnamed: C32.2, IC2.A2 (REG)
unnamed: J4.A5 (CC1), R1_USB.2
unnamed: J4.B5 (CC2), R2_USB.1
unnamed: EPD_C2.2, J1.4
unnamed: EPD_C1.2, J1.5
unnamed: EPD_C6.2, J1.18
unnamed: EPD_C7.2, J1.19
unnamed: EPD_C8.2, J1.20
unnamed: EPD_C10.2, J1.22
unnamed: EPD_C12.2, J1.24
OUT+: IC2.A3 (OUT+), TP_OP.TP
OUT-: IC2.C3 (OUT-), TP_ON.TP
P0.04: U1.P$J1 (P0.04/AIN2)
P0.09: U1.P$L24 (P0.09/NFC1)
P0.13/1.5D: C30.2, R5.1, SW_UP.2
P0.13/2.6C: U1.P$AD8 (P0.13)
P0.14/1.5D: C31.2, R8.1, SW_ENT.2
P0.14/2.7C: U1.P$AC9 (P0.14)
P0.19: U1.P$AC15 (P0.19)
P0.20: U1.P$AD16 (P0.20)
P0.21: U1.P$AC17 (P0.21)
P0.22: U1.P$AD18 (P0.22)
P0.23: U1.P$AC19 (P0.23)
P0.24: U1.P$AD20 (P0.24)
P0.25: U1.P$AC21 (P0.25)
P0.26: U1.P$G1 (P0.26)
P0.27: U1.P$H2 (P0.27)
P0.28: U1.P$B11 (P0.28/AIN4)
P0.29: U1.P$A10 (P0.29/AIN5)
P0.30: U1.P$B9 (P0.30/AIN6)
P0.31: U1.P$A8 (P0.31/AIN7)
P1.01/1.6C: Q1.1 (G), R_PWR_EPD.1
P1.01/2.4B: U1.P$Y23 (P1.01)
P1.02/1.6C: C29.2, R7.1, SW_DN.2
P1.02/2.8C: U1.P$W24 (P1.02)
P1.03: U1.P$V23 (P1.03)
P1.04: U1.P$U24 (P1.04)
P1.05: U1.P$T23 (P1.05)
P1.06: U1.P$R24 (P1.06)
P1.07: U1.P$P23 (P1.07)
P1.09: U1.P$R1 (P1.09)
P1.10: U1.P$A20 (P1.10)
P1.11: U1.P$B19 (P1.11)
P1.12: U1.P$B17 (P1.12)
P1.13: U1.P$A16 (P1.13)
P1.14: U1.P$B15 (P1.14)
P1.15: U1.P$A14 (P1.15)
PMIC_INT: IC1.A1 (!INT), U1.P$T2 (P0.11)
PREVGH: EPD_C9.2, J1.21
PREVGL: D2.2 (A), EPD_C11.2, J1.23
RESE: J1.3, Q3.2 (S), R1_EP_DR.2
RESET: J2.6, TP_RESET.TP, U1.P$AC13 (P0.18/RESET)
SCK/1.5B: J1.13
SCK/2.2D: U1.P$A12 (P0.02/AIN0)
SCL/1.4C: IC2.C1 (SCL), U2.7 (SCL)
SCL/2.4C: IC1.B1 (SCL), IC3.12 (SCX), R4.2, R17.2, TP_SCL.TP, U1.P$M2 (P0.07)
SDA/1.4C: IC2.B2 (SDA), U2.8 (SDA)
SDA/2.4C: IC1.C1 (SDA), IC3.2 (SDX), R2.2, R18.2, TP_SDA.TP, U1.P$L1 (P0.06)
SWDCLK: J2.4, TP_SWDCLK.TP, U1.P$AA24 (SWDCLK)
SWDIO: J2.2, TP_SWDIO.TP, U1.P$AC24 (SWDIO)
SWO: TP_SW0.TP, U1.P$AD22 (P1.00)
VBAT/1.2A: C27.2, TP_VBAT.TP, U2.2 (CELL), U2.3 (VDD)
VBAT/2.5C: C37.2, IC1.C2 (BAT)
VBUS/1.5D: C42.1, C43.1, D3.5 (VBUS), J4.A4_B9 (VBUS), J4.A9_B4 (VBUS)
VBUS/2.6D: C21.1, C38.2, IC1.A2 (IN), U1.P$AD2 (VBUS)
VREG: C23.2, C24.2, C39.1, IC1.B2 (SYS), IC9.A1 (EN), IC9.A2 (VIN_1), IC9.A3 (VIN_2), TP_VREG.TP

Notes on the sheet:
LiPo Charger
DC/DC
IMU
SWD
DEC1
P0.00/XL1
P0.00/XL2
DEC3
DEC4_6
E-Paper & Pheripherals
Haptic Driver
Buttons
USB C Connector & ESD Protection
E-Paper Display Connector
Fuel Gauge
E-Paper Drive Circuit
DMG2305UX-7
MCU, Power IMU, SWD
drawn by: Adelina Alexe
InkTime v6
28.03.2026 21:12
1/2
2/2

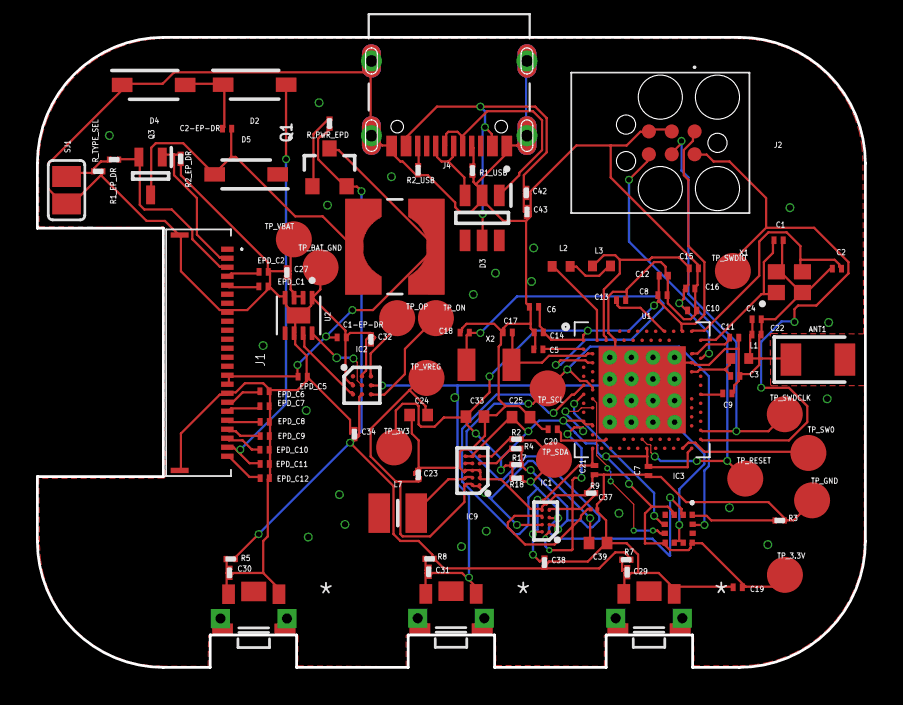
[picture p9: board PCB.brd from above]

Board: 2 copper layers, 46.0 x 35.0 mm, 105 parts (0 on the bottom side), 65 nets.

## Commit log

2026-04-10 Initial commit with project structure
    [PCB_2D.brd, Schematic.sch]
2026-04-17 Changed issued files and aditional modifications
    [PCB.brd]
2026-04-17 Added schematic in pdf format

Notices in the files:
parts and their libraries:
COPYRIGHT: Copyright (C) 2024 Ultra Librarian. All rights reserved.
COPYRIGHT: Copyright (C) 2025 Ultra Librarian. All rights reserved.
